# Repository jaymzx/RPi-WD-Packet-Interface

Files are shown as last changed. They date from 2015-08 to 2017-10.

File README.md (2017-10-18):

# RPi-WD-Packet-Interface - A digital mode soundcard interface for the Raspberry Pi!

I set up an APRS igate using a Raspberry Pi device and a TNC-Pi 'hat'. While troubleshooting some other issues, I inadvertantly damaged the TNC-Pi, so I decided to go with a software TNC application. In this case, I chose [Dire Wolf](https://github.com/wb2osz/direwolf) by WB2OSZ. In his documentation, he specified a simple radio PTT interface that included a 'watchdog timer' to prevent a software issue from locking the radio into transmit. Working with WB2OSZ, I expanded the circuit and created a board with the following features:

### Selectable transmit and receive channels
* I noticed between sound card dongles, the mic input could be on the left or the right channel, depending on how much care the manufacturer put into it. A jumper lets you pick the channel that works with your card. I added a transmit channel selector for the same reason, but also so you can use a 'Y' cable with your stereo sound card and use two interfaces to work with two radios without any cable hacking.

### Transmit audio level pot
* The radio is expecting millivolts of input into its MIC input. Modern sound cards can put out more than 2V peak to peak. This is really bad for distortion and over-deviation. Right now, I use about 40% volume on the sound card, and 20% volume on the pot. The audio is DC isolated with a capacitor to prevent phantom voltage (for electret microphones) from either the sound card or the radio from damaging anything.

### Adjustable watchdog delay
* Most people will use this for packet, but some others may use it for things like RTTY, JT-65, QRSS or any other digital mode that has a long duty cycle. I added a big cap and 25-turn trimmer for a delay adjustable between 0 and 110 seconds with the parts specified. One can solder in a fixed resistor or change values for something that doesn't need to be adjusted. [Calculators](http://www.ohmslawcalculator.com/555-monostable-calculator) are out there.

### DCD (received packet) LED
* The newest version of Dire Wolf can trigger a GPIO pin to signal a successfully decoded packet. Just bring this pin 'high' and the yellow DCD LED will light up. Yay. Good for watching activity at-a-glance from across the shack.

### Selectable single-wire handheld PTT or 'Kenwood' dedicated PTT wire method
* Most HTs use a resistor to ground on the microphone input to trigger PTT. Kenwood/Baofeng and some others have to be different and ground the mic shield to trigger. You can set a jumper to select whatever method you need.
	
### Standard Kantronics DB-9 radio interface
* I already had some cables I made and bought for radios when using my KPC3. The TNC-Pi and (I believe) the TinyTrak and OpenTracker devices use the same standard. This makes it easy to buy cables if you don't want to make them, or re-use ones you already have kicking around. FWIW, I hate DB9 connectors and prefer RJ-45 for these purposes, but I wanted to make it 'standard'. Signalink and RigBlaster use a similar (although RB is reversed) RJ-45 standard, but it's not as prolific. In case someone hates DB-9 as much as I do, I called out the signals on the pads to which they can be directly soldered for a cable, header pins, etc.

### Native 3.3v Rpi logic levels
* Using this board as configured works with the 3.3v logic the RPi uses. If you use another controller (like an Arduino) you *can* use 5V logic as the LMC555 CMOS can handle it without a sweat, but you will need to change the resistor values for the LEDs and transistor bias. You can also skip 3.3v altogether if you want to use it with a 5V microcontroller and use a cheap and widely-available LM555N (and the appropriate resistor changes).

### Uses standard 60mm x 60mm 'Sick of Beige' PCB size
* Just like the [xkcd](https://xkcd.com/927/) comic about standards, there is a new PCB size standard for the Maker crowd called [Sick of Beige](http://dangerousprototypes.com/docs/Sick_of_Beige). They have some cool acrylic cases at [Seeed Studios](http://www.seeedstudio.com/depot/Sick-Of-Beige-Basic-Case-v1-60mm-Square-DP6060-p-1329.html), but you can probably find others or fab up your own. The original board was smaller, but in order to fit into the SoB standard size, the minimum size that would fit the DB-9 connector is 60mm. Please note this is *not* a 'hat' for the RPi. It's a separate board. 

### Open Hardware
* I put the time into it, but like most of my projects, once it's done, it's done. I figure others can benefit from my work, so I may as well pass it on. This project is licensed under [Creative Commons Attribution-ShareAlike](https://creativecommons.org/licenses/by-sa/3.0/), so you can edit it, improve it, remix it into another project, make and sell PCBs or kits, etc. You just need to specify a link back to the original source (here) to comply. It's no big deal.
		
### Readily-available parts
* You probably have most of these parts in your bin, but things like the 3.5mm and DB-9 connectors are available at [SparkFun](https://www.sparkfun.com/). I specified genuine Borne trimpots in the PCB footprints but they are commonly used by others. You can find them at [Mouser](http://www.mouser.com/) or many other places.

You can order a [pre-made PCB from OSH Park](https://oshpark.com/shared_projects/dotsia3r) (with the beautiful purple solder mask as shown). They come in multiples of three, so order some for your friends or make a couple for a multi-rig interface. You can also take the Eagle files and have them made elsewhere, or make your own using a toner transfer or photo etch PCB process. Go nuts.

# Known issues
None at this time. 

# Improvements
I'm kicking around the idea of an RJ-45 version of this board, which would be a simple redesign. I also have on the drawing board an isolated version with transformers and opto-isolated PTT control. I welcome discussion around this, and if you can't wait, feel free to fork this project!

## Enjoy the interface, and see you on the air.

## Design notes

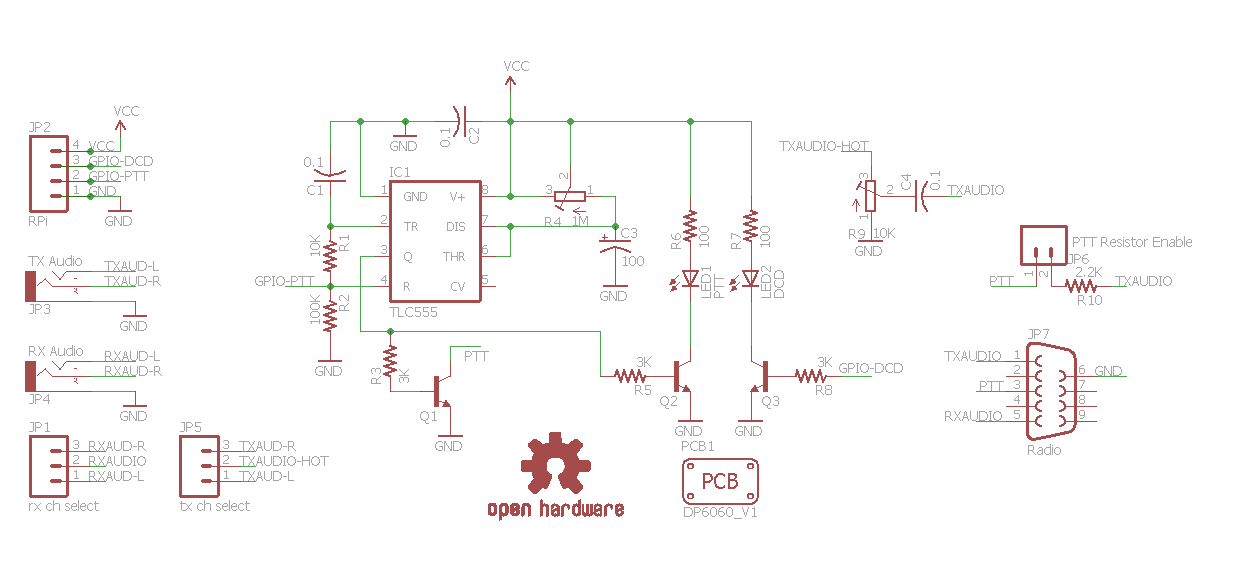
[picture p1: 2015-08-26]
Schematic v1.1.png

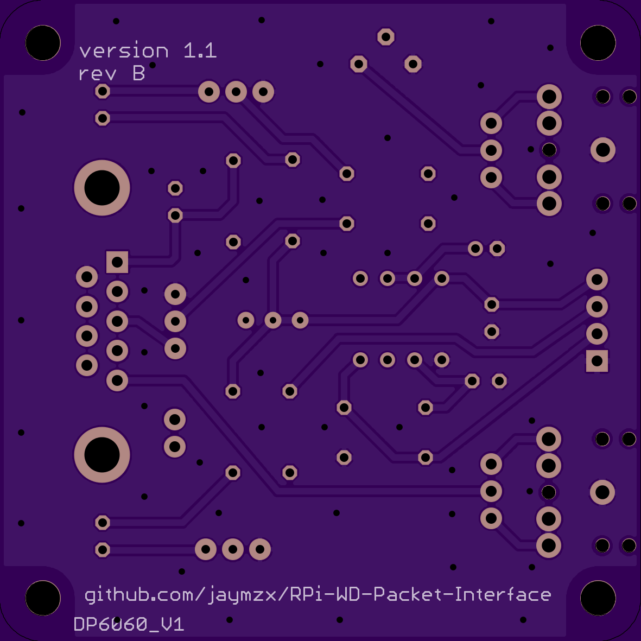
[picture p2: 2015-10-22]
RPi WD Packet Interface 9pinDSub v1.1 Rev B Final - Render - Bottom.png

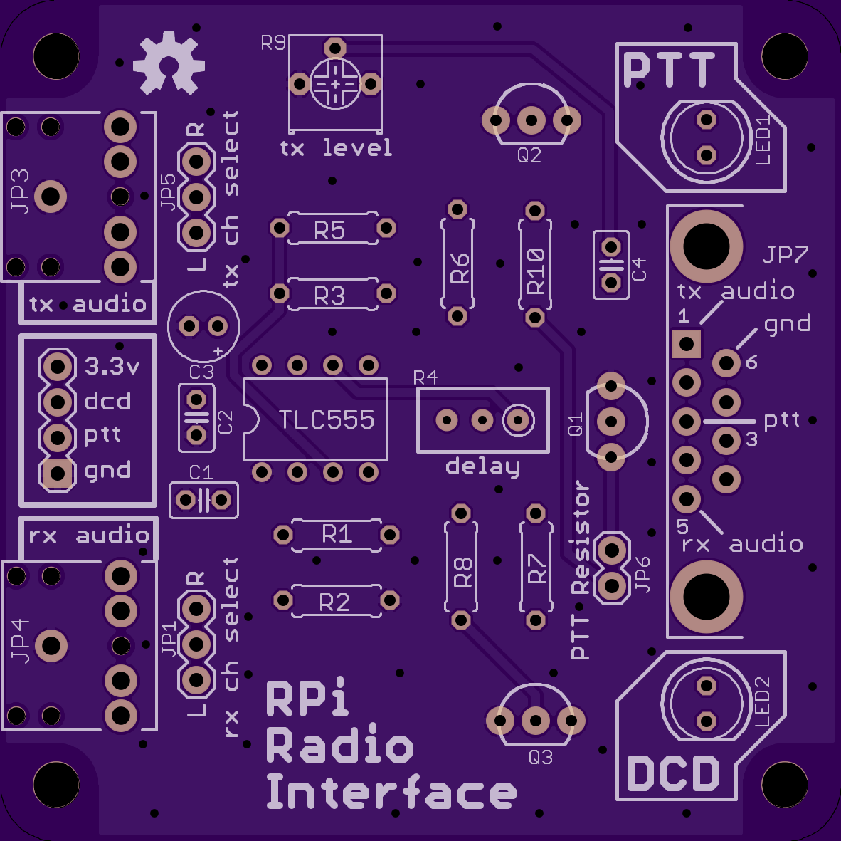
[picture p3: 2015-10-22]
RPi WD Packet Interface 9pinDSub v1.1 Rev B Final - Render - Top.png

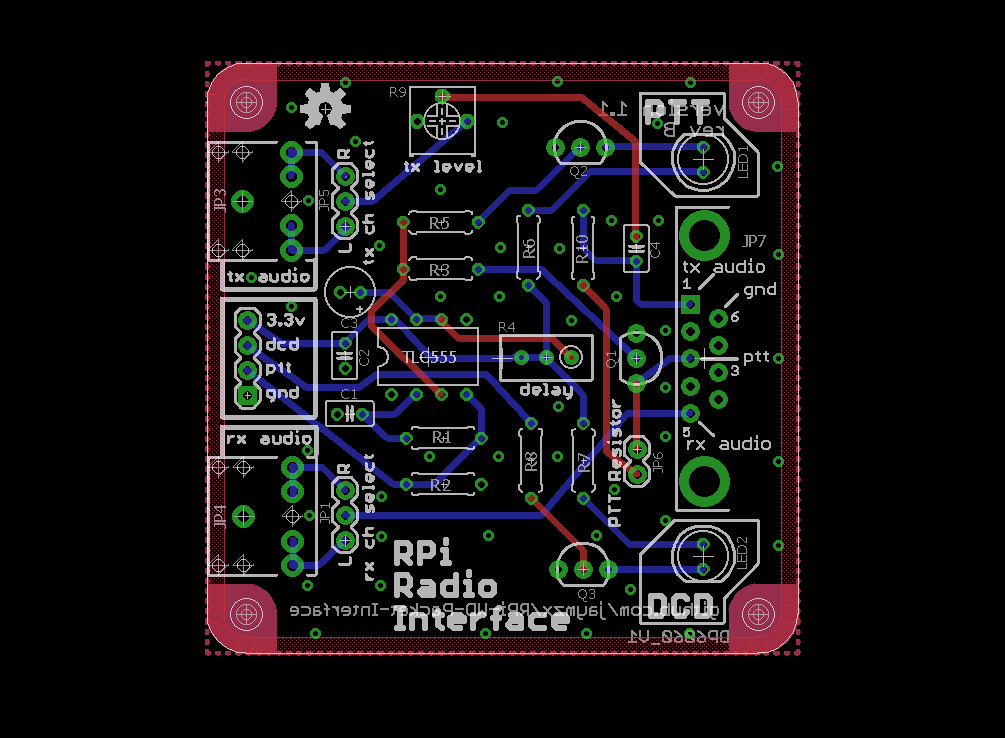
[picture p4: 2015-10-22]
RPi WD Packet Interface 9pinDSub Layout v1.1 Rev B Final.png

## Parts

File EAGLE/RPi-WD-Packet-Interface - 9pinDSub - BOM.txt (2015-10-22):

Part Value               Device                   Package      Description                                               

C1   0.1                 C-US025-025X050          C025-025X050 CAPACITOR                             
C2   0.1                 C-US025-025X050          C025-025X050 CAPACITOR                              
C3   100uf               CPOL-USE2-5              E2-5         POLARIZED CAPACITOR                      
C4   0.1                 C-US025-025X050          C025-025X050 CAPACITOR                                
IC1  TLC555              TLC555                   DIL08        TIMER 3.3V                                                    
JP1  rx ch select        M03PTH                   1X03         Standard 3-pin 0.1" header                            
JP2  RPi                 M04PTH                   1X04         Standard 4-pin 0.1" header                                
JP3  TX Audio            AUDIO-JACKPTH            AUDIO-JACK   3.5mm Audio Jack; Sparkfun PRT-08032 or equiv              
JP4  RX Audio            AUDIO-JACKPTH            AUDIO-JACK   3.5mm Audio Jack; Sparkfun PRT-08032 or equiv               
JP5  tx ch select        M03PTH                   1X03         Standard 3-pin 0.1" header                                   
JP6  PTT Resistor Enable M02PTH                   1X02         Standard 2-pin 0.1" header                      
JP7  Radio               DB9FEMALE                DB9          DB9 Connector; Sparkfun PRT-00429 or equiv                 
LED1 PTT                 LED5MM                   LED5MM       T1-3/4 Red LED                                               
LED2 DCD                 LED5MM                   LED5MM       T1-3/4 Yellow LED                                             
Q1   PTT                 TRANSISTOR_NPNTO-92      TO-92        Generic NPN BJT 2N3904 or equiv                              
Q2   PTT-LED             TRANSISTOR_NPNTO-92      TO-92        Generic NPN BJT 2N3904 or equiv                              
Q3   DCD-LED             TRANSISTOR_NPNTO-92      TO-92        Generic NPN BJT 2N3904 or equiv                            
R1   10K                 R-US_0207/7              0207/7       RESISTOR                                 
R2   100K                R-US_0207/7              0207/7       RESISTOR                               
R3   3.3K                R-US_0207/7              0207/7       RESISTOR                               
R4   1M                  R-TRIMM3296W             RTRIM3296W   BOURNS 3296 - Vertical 3/8" Square Trimpot® 25-turn Trimming Potentiometer                                         
R5   3.3K                R-US_0207/7              0207/7       RESISTOR                                 
R6   100                 R-US_0207/7              0207/7       RESISTOR                                 
R7   100                 R-US_0207/7              0207/7       RESISTOR                                
R8   3.3K                R-US_0207/7              0207/7       RESISTOR                               
R9   10K                 RTRIM-3362P              RTRIM3362P   BOURNS 3362 - 1/4" Square Trimpot® Trimming Potentiometer 
R10  2.2K                R-US_0207/7              0207/7       RESISTOR

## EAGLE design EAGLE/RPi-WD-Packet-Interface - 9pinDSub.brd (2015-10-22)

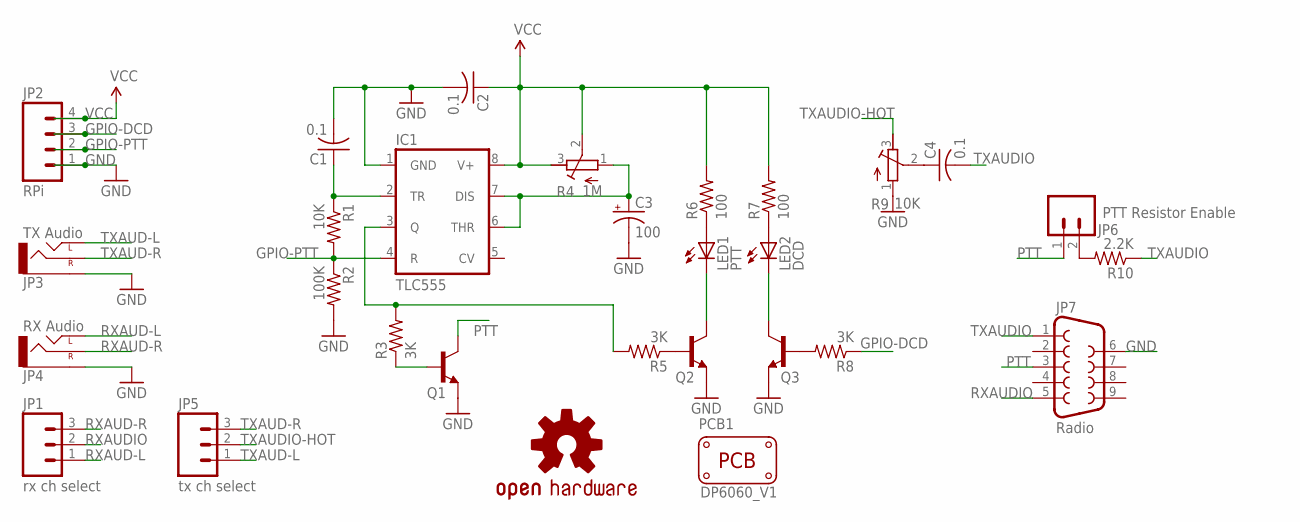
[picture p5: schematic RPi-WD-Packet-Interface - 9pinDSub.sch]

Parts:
C1, C2, C4: 0.1; C025-025X050
C3: 100; E2-5
IC1: TLC555; DIL08
JP1: rx ch select; 1X03
JP2: RPi; 1X04
JP3: TX Audio; AUDIO-JACK
JP4: RX Audio; AUDIO-JACK
JP5: tx ch select; 1X03
JP6: PTT Resistor Enable; 1X02
JP7: Radio; DB9
LED1: PTT; LED5MM
LED2: DCD; LED5MM
LOGO1: OSHW-LOGOM; OSHW-LOGO-M
PCB1: PCB_DP_SQUARE-6X6; DP6060_V1
Q1: PTT; TO-92-AMMO
Q2: PTT-LED; TO-92-AMMO
Q3: DCD-LED; TO-92-AMMO
R1: 10K; 0207/7
R2: 100K; 0207/7
R3, R5, R8: 3K; 0207/7
R4: 1M; RTRIM3296W
R6, R7: 100; 0207/7
R9: 10K; RTRIM3362P
R10: 2.2K; 0207/7

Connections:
GND: C1.2, C2.2, C3.-, IC1.1 (GND), JP2.1, JP3.SLEEVE, JP4.SLEEVE, JP7.6, Q1.1 (E), Q2.1 (E), Q3.1 (E), R2.2, R9.1
GPIO-DCD: JP2.3, R8.1
GPIO-PTT: IC1.4 (R), JP2.2, R1.2, R2.1
unnamed: LED1.A, R6.1
unnamed: LED2.A, R7.1
unnamed: C1.1, IC1.2 (TR), R1.1
unnamed: C4.1, R9.2
unnamed: C3.+, IC1.6 (THR), IC1.7 (DIS), R4.1 (A)
unnamed: LED1.K (C), Q2.3 (C)
unnamed: Q2.2 (B), R5.1
unnamed: Q1.2 (B), R3.1
unnamed: LED2.K (C), Q3.3 (C)
unnamed: Q3.2 (B), R8.2
unnamed: JP6.2, R10.2
PTT: JP6.1, JP7.3, Q1.3 (C)
PTT_TRIGGER: IC1.3 (Q), R3.2, R5.2
RXAUD-L: JP1.1, JP4.TIP (LEFT)
RXAUD-R: JP1.3, JP4.RING (RIGHT)
RXAUDIO: JP1.2, JP7.5
TXAUD-L: JP3.TIP (LEFT), JP5.1
TXAUD-R: JP3.RING (RIGHT), JP5.3
TXAUDIO: C4.2, JP7.1, R10.1
TXAUDIO-HOT: JP5.2, R9.3
VCC: C2.1, IC1.8 (V+), JP2.4, R4.2 (S), R4.3 (E), R6.2, R7.2

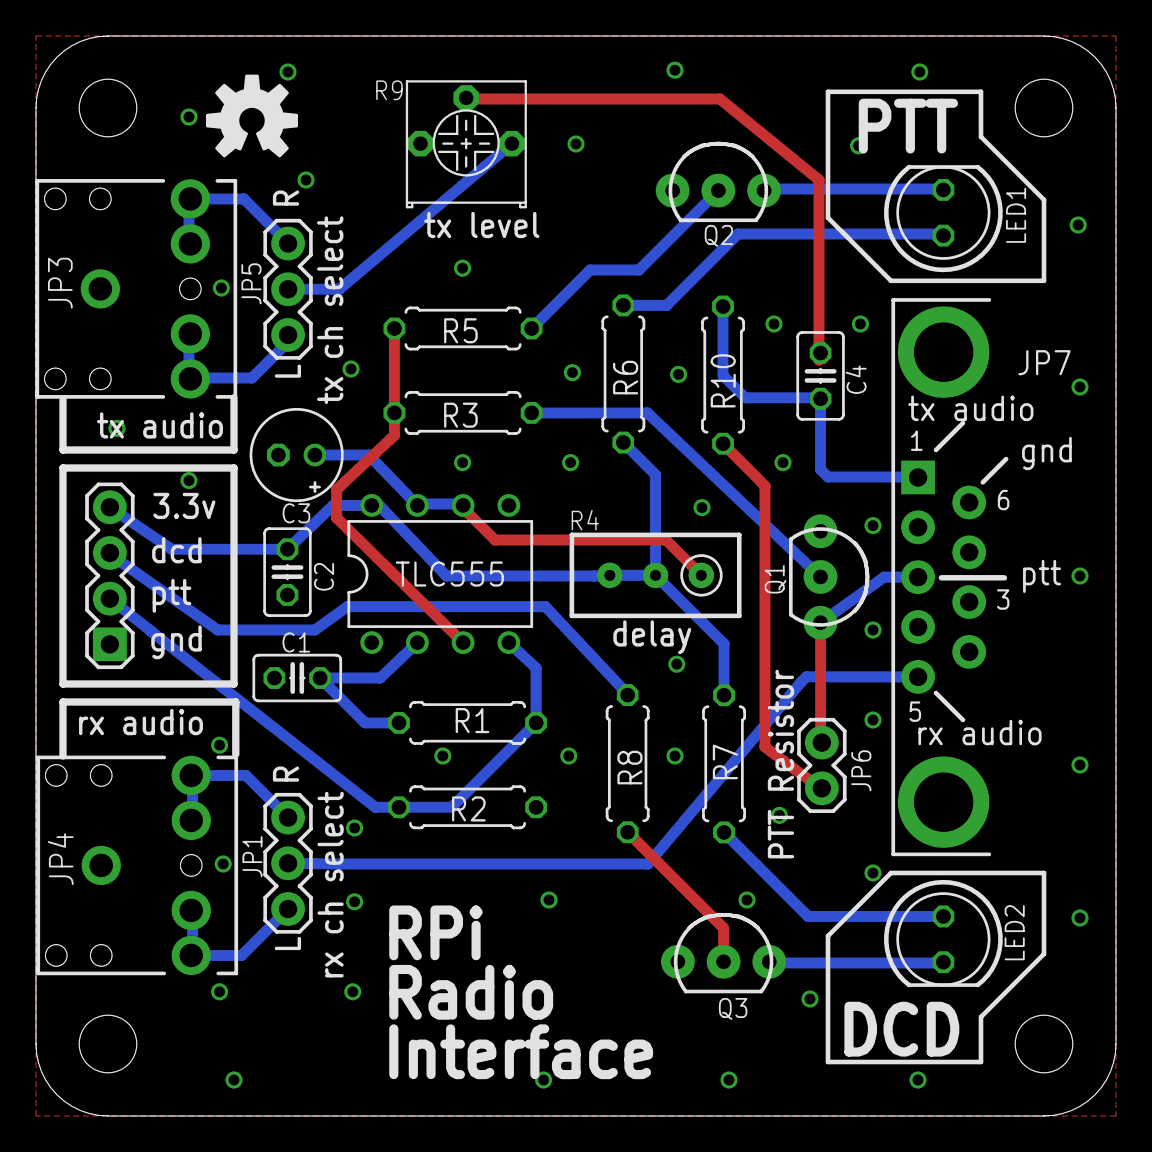
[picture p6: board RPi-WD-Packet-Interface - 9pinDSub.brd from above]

Board: 2 copper layers, 60.0 x 60.0 mm, 29 parts (0 on the bottom side), 24 nets.

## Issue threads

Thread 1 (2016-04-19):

I can't find a match for Device #'s in BOM

ikanode, 2016-04-19:
I can't find a match for most of the Device #'s in the BOM.  For example:
C1 is show as 0.1  I assume that some sort of 0.1 uf capacitor but what kind, what specs, what size.  An internet search on Device #'s and Package numbers only finds matches for  PCB layout programs.

How do I order parts that will work and that will fit on the circuit board?

Thanks,
Irv

jaymzx, 2016-04-23:
Sorry for the confusion. 0.1 is indeed 0.1uf, and is a standard ceramic capacitor. The dimensions in the BOM are exported from Eagle, so they refer to the footprint size. For the 0.1uf ceramic caps, that is 2.5x5.0mm. You can use whatever you have available, however, I recommend something at least 16V. Most ceramics that size begin around 50V. All resistors are 1/8 or 1/4W, whatever you have handy.

Closed 2017-10-07.

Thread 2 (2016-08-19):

All-in-one enhancement

bnordgren, 2016-08-19:
I think it may be valuable to have a single USB cable connect you to:
1. A sound card connected directly to a radio interface (on PCB)
2. A GPS
3. An extra USB port (to replace the one consumed by this peripheral)

This may go a ways to reduce the cabling, and/or make it possible to use everything from a Raspberry Pi Zero to a router running OpenWRT to a desktop computer.

kg5ebi, 2016-12-05:
A USB 1:7 hub controller IC costs only $1 to add. A CM108 IC is about the same cost. I think an improvement would be to have the LED contacts coming off the board as female headers because the LED's likely would be routed elsewhere in the project and the board not always visible.

JayMZX what size of donation would it take to make these few mods a possibility?

bnordgren, 2017-01-04:
@kg5ebi I'm adopting some of this as a part of a larger APRS project for 2017. [1]  I think I'm going to leave the GPS as an external USB peripheral, but I like your suggestion as to sound card chip and USB hub chip. It also occurs to me that powerpole connectors on this device could be what ultimately provides power to the Pi via USB. If you'd like to participate or track progress, my fork of this repository may be the right place. I've started to triage some of the improvements into discrete issues. Your comments, suggestions, and/or efforts are welcome.

Closing this issue to let @jaymzx move on. ;)

73, AF7RQ

[1] http://www.mineral-ares.org/blog/wifi-hotspot-aprs-web-mapper

Closed 2017-01-04.

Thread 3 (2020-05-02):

Parts from BOM

cbr600, 2020-05-02:
I have downloaded the files, the BOM, purchased the PCB, imported them in Eagle, but there's no actual information on parts to use.  The numbers and values work from some parts but not all (eg. capacitors).  How many watts the resistors need to take? etc.

How do I get to purchasing the needed parts? Sorry for posting here but could not reach the author otherwise.

hsand, 2020-05-07:
I had the same question, but found some clarifications on a previously closed issue: https://github.com/jaymzx/RPi-WD-Packet-Interface/issues/1

cbr600, 2020-05-07:
Wow. Your search Fu is strong. I looked all over.  Or so  I thought...

Thanks!

Closed 2020-05-07.

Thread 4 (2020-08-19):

Any leads on a case, since seeedstudio doesn't seem to carry them any more?

rfugina, 2020-08-19:
ALL of the Sick of Beige cases seem to be out of stock at seeedstudio, giving me the impression they weren't making enough money from them.  Any other leads on a case/cover for this?

hsand, 2021-03-21:
I wasn't able to find any cases either, but I used [this repository](https://github.com/psmay/sick-of-beige-svg) to generate SVG files and had custom boards printed at Elecrow.

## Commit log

2015-06-28 First EAGLE commit
    Initial commit with schematic, board and bill of materials.
    [RPi-WD-Packet-Interface - 9pinDSub.brd, RPi-WD-Packet-Interface - 9pinDSub.sch]
2015-06-28 Update JP part numbers, new BOM export
    [RPi-WD-Packet-Interface - 9pinDSub.brd, RPi-WD-Packet-Interface - 9pinDSub.sch]
2015-06-29 Updates after first assembly
    Added DCD LED bias resistor, text, widened board for additional mount
    hole clearance.
    [RPi-WD-Packet-Interface - 9pinDSub.brd, RPi-WD-Packet-Interface - 9pinDSub.sch]
2015-07-11 Design update to v1.1
    Added channel selection jumpers for RX/TX, single-line PTT resistor
    jumper, TX audio level pot, timeout delay pot (0-2 mins /w specified
    values). Moved to Dangerous Prototypes 'Sick of Beige' 60mm x 60mm PCB
    layout standard.
    [RPi-WD-Packet-Interface - 9pinDSub.brd, RPi-WD-Packet-Interface - 9pinDSub.sch]
2015-07-30 Update RPi-WD-Packet-Interface - 9pinDSub - BOM.txt
2015-08-16 Update OSH Park URL for Rev A PCB
2015-08-26 Update PCB to v1.1a, add images of board and schematic
    [RPi-WD-Packet-Interface - 9pinDSub.brd, RPi-WD-Packet-Interface - 9pinDSub.sch]
2015-08-26 Fix BOM
2015-10-22 Update repo to board revision B
    [RPi-WD-Packet-Interface - 9pinDSub.brd, RPi-WD-Packet-Interface - 9pinDSub.sch]
2015-10-22 Update BOM for clarification, add part numbers

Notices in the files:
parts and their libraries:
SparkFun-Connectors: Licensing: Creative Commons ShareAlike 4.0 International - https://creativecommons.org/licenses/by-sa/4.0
